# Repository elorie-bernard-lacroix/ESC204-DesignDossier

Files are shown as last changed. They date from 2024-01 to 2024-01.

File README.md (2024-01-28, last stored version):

# ESC204-DesignDossier
A collection of documents, which provide evidence for our design process, design outcomes, and collaboration process for the ESC204 Prototyping Skills Assignment.

Contents and Important Files:
-> 1 - Framing and Initial Ideas
    -> Material here is about the protective case. Iterative design for code/circuitry was started without initial framing
-> 2 - Code and Circuitry
    -> Includes final code (code_final.py) and circuitry (circuit_diagram_final.png)
    -> Code/breadboard layout iterations
    -> Calculations and design decisions described in resistor_calculations.rtf and update_log.rtf
-> 3 - CAD+CAM, MyFab Submission
    -> 
-> 4 - Testing
    -> 
-> 5 - Final Product
    ->

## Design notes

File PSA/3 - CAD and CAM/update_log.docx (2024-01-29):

Update Log – CAD + CAM

Jan 20, 2024

- Started measurements of the board based on Jessica’s design and added it to my pre-existing document from a studio (where we measured the dimensions of the breadboard)
- Found some potential boxes and chose the one outlined in the file “boxes.py_reference”. This box was chosen because of its simplicity and compactness (contributing the usability performance objective). I also specifically chose laser cutting because it had a good chance of being faster and for the aesthetic.
- Looked through the boxes.py export, imported it into Fusion360 (psa-parts) and added the holes corresponding with the lights, the button, and the micro-USB. For this part, simplicity was prioritized, to make sure the result once it was printed was predictable and adjustable (easy to modify) if needed.
- The parts were extruded and uploaded to a second Fusion file (the psa-assembly). I started to assemble them.

Jan 21, 2024

- I finished assembling the parts and realized I could add in an extra component to secure the bread board easily into place. I added holes in the inner sides that fit perfectly with the breadboard attachments and added and inner side in the back of the box for the attachments on that side (the attachment holes only corresponded to the attachments that stook out of the breadboard – so 2 out of 4 sides which is enough to hold it in place, combined with snugness of fit everywhere else).
- This was updated in the Fusion assembly file
- I added the button as well, along with some circular caps that we could try out once it was laser cut.
- I sent the file back to Jessica so she could check over the measurements.
- I exported and imported into AutoCAD, used the MyFab template and made sure everything was up to MyFab expectations (in the correct layer, etc).
- I submitted to MyFab (order: Las7310)

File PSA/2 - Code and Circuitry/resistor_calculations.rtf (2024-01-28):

⁃ current-limiting resistance formula: (actual voltage - forward voltage)/current
⁃ from Pico spec sheet: max current, actual voltage
⁃ from LED spec sheets: min current, forward voltage

RED LED (spec sheet https://cdn-shop.adafruit.com/datasheets/WP7113SRD-D.pdf)
⁃ target luminous intensity relative to 20mA: 0.2
⁃ max current: 14mA
⁃ fwd voltage: 1.82V
⁃ actual voltage: 2.62V
⁃ current-limiting resistance: (2.62-1.82 V)/0.014 A = 57 ohms
⁃ min current: 3mA
⁃ fwd voltage: 1.75V
⁃ actual voltage: 3.1V
⁃ current-limiting resistance: (3.1-1.75 V)/0.003 A = 450 ohms
⁃ valid resistor range: 57-450 ohms
⁃ resistor chosen: 220 ohms

GREEN LED (spec sheet https://www.kingbrightusa.com/images/catalog/SPEC/WP7113SGD.pdf)
⁃ target luminous intensity relative to 20mA: 0.2
⁃ max current: 14mA
⁃ fwd voltage: 2.2V
⁃ actual voltage: 2.62V
⁃ current-limiting resistance: (2.62-2.2)/0.014 = 30 ohms
⁃ min current: 4mA
⁃ fwd voltage: 2V
⁃ actual voltage: 3.1V
⁃ current-limiting resistance: (3.1-2)/0.004 = 275 ohms
⁃ valid resistor range: 30-275 ohms
⁃ resistor chosen: 220 ohms

BLUE LED (spec sheet https://www.kingbrightusa.com/images/catalog/SPEC/WP7113LVBC-D.pdf)
⁃ target luminous intensity relative to 2mA: 0.5
⁃ max current: 14 mA
⁃ fwd voltage: 3.2V
⁃ actual voltage: 2.62V
⁃ current-limiting resistance: (2.62-3.2)/0.014 = -41.4 ohms (ie. resistor not needed)
⁃ min current: 1 mA
⁃ fwd voltage: 2.5V
⁃ actual voltage: 3.25V
⁃ current-limiting resistance: (3.2-2.5)/0.001 = 750 ohms
⁃ valid resistor range: 0-750 ohms
⁃ resistor chosen: 330 ohms (since blue LED is very bright even at low relative intensity)

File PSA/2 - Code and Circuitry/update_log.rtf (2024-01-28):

Jan 19, 2024
- resistance calculations done, followed Lab 1 procedure

Jan 20, 2024
- trying some possible circuit layouts on the breadboard.
- the blue and red LEDs turn on/off at the same time — try pairing them on the breadboard?
- wrote code to achieve the required 3-state toggle system. very straightforward. used a “pressed” variable to ensure that states change only when button is initially pressed (and not when button is held down, released, etc.). linked blue and red LEDs to the same GPIO pin.
- putting the blue and red LEDs in series together with a 220 ohm resistor didn’t work (the blue LED lit up, but not the red). this could be because the resistance used was too high to reach the minimum current requirement for red (~3mA). since 220 ohms is the lowest resistance provided, it’ll be better to put all 3 LEDs separate with their own resistor.
- rewrote code using 3 GPIO pins for LEDs, to reflect the new circuit layout. circuit is working!
- sent pics of circuit layout to Elorie so that she can start the CAD.

Jan 24, 2024
- in myfab. replaced jumper wires with actual wires. had to be careful with wire length so that they lay flat on the breadboard.
- used black wires for ground, red for everything else
- moved button closer to Pico to match up with button presser positioning on lasercut box.
- circuit done!

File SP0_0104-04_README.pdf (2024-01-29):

# ESC204-DesignDossier

A collection of documents, which provide evidence for our design process, design outcomes, and collaboration process for the ESC204 Prototyping Skills Assignment.

Contents and Important Files:
-> 1 - Framing and Initial Ideas
-> Material here is about the protective case. Iterative design for code/circuitry was started without initial framing
-> 2 - Code and Circuitry
-> Includes final code (code_final.py) and circuitry (circuit_diagram_final.png)
-> Code/breadboard layout iterations
-> Calculations and design decisions described in resistor_calculations.rtf and update_log.rtf -> 3 - CAD and CAM
-> Includes the use of the resource, boxes.py (boxes.py_reference.pdf)
-> Includes CAD model of structural elements (psa-parts.stp), their assembly (psa-assembly.stp) and screenshot of the assembly (screenshot_psa-assembly_CAD_model.png)
-> Includes as-built CAM model (MyMaker_LasercutPlywood3mm_Autocad_mm.dwg) and screenshot (screenshot_CAM_model.png)
-> Design decisions described (update_log.docx)
-> Screenshot of confirmation email from MyFab for the Laser cutting order (MyFab confirmation_email.png)
-> 4 - Systems Integration and Testing
-> videos of testing functionality (pressing the button for the lights, assembly and disassembly, rattling, plugging and unplugging micro-USB)
-> videos of testing edge cases (pressing button and holding it, pressing the button very fast) -> Update log to show the process of assembling, modifying, and testing (update_log.docx) -> 5 - Final Product
-> Top, side, and front view of the final product
-> Orthographic picture of the final product, open with visible circuit

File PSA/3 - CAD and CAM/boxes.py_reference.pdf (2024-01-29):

The chosen design from boxes.py was the cardbox with the following measurements

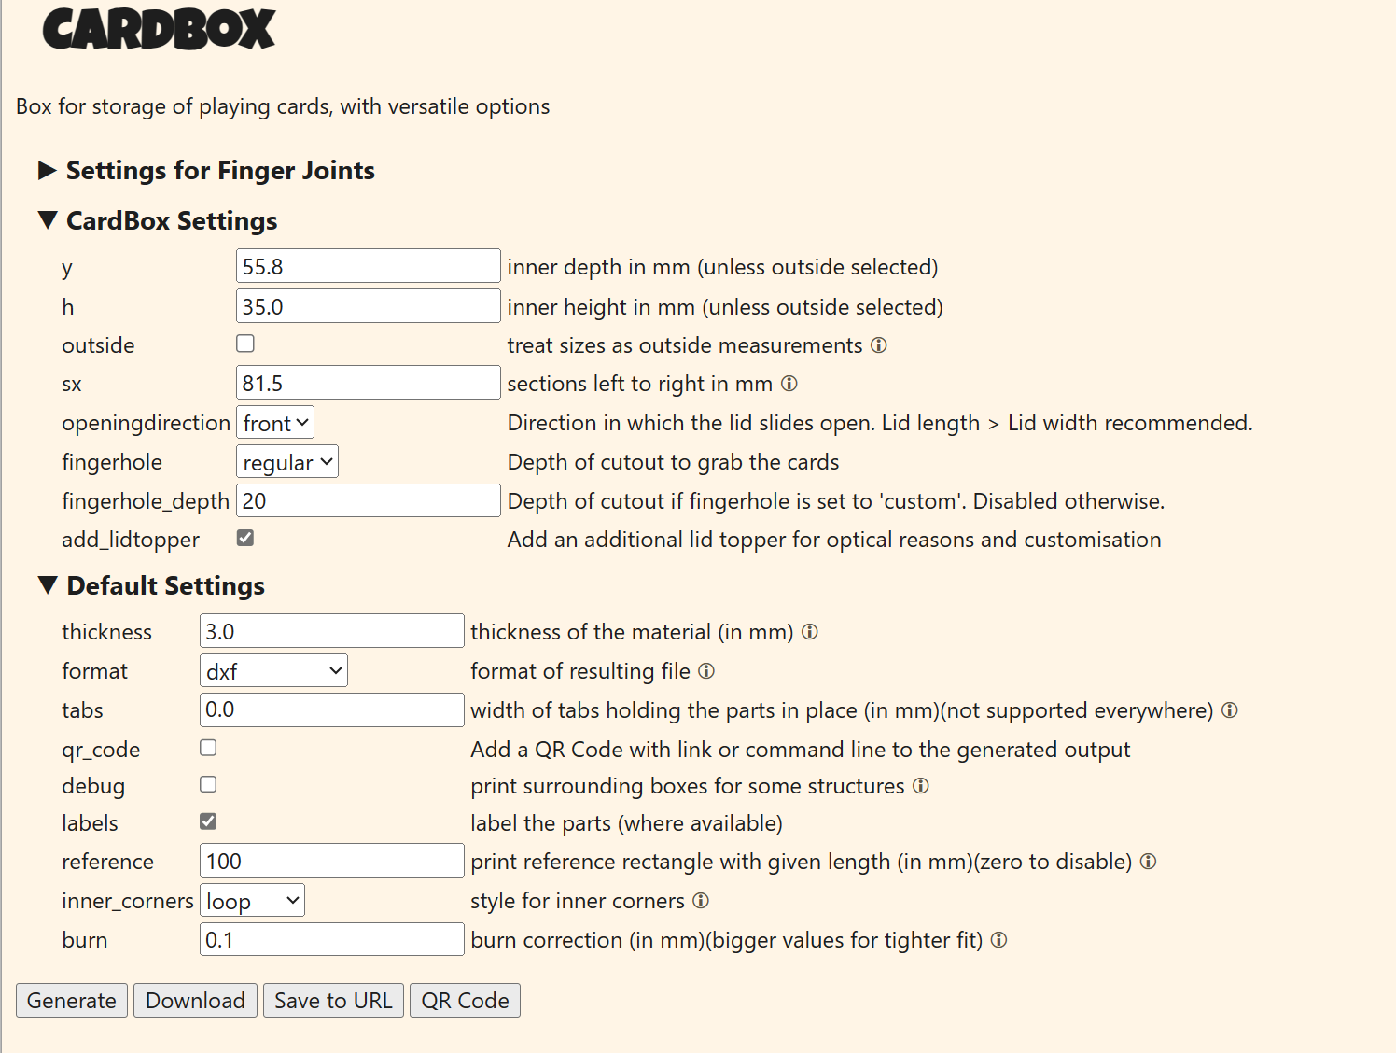
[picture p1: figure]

Design imported into CAD, before adaptations

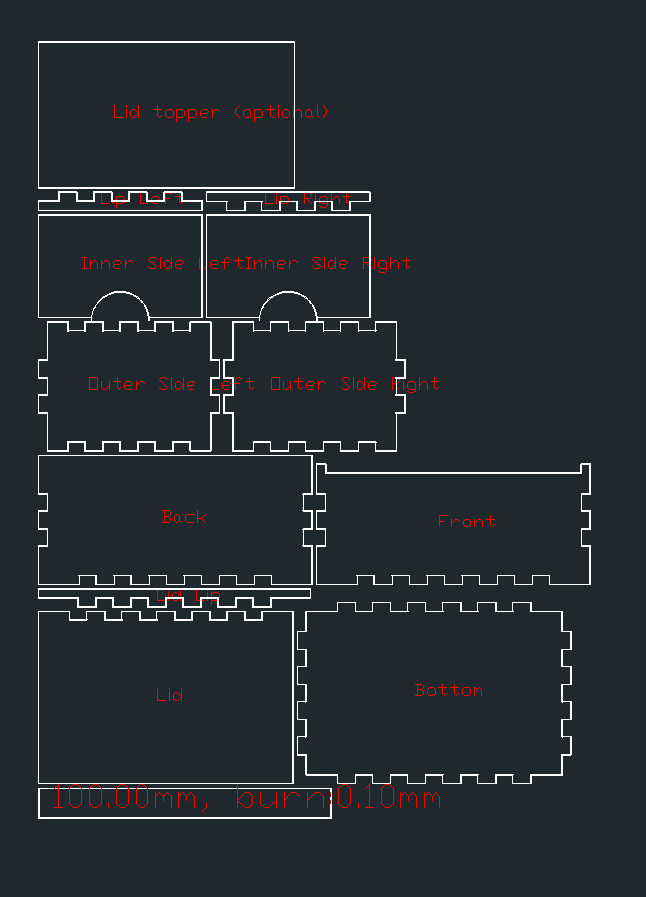
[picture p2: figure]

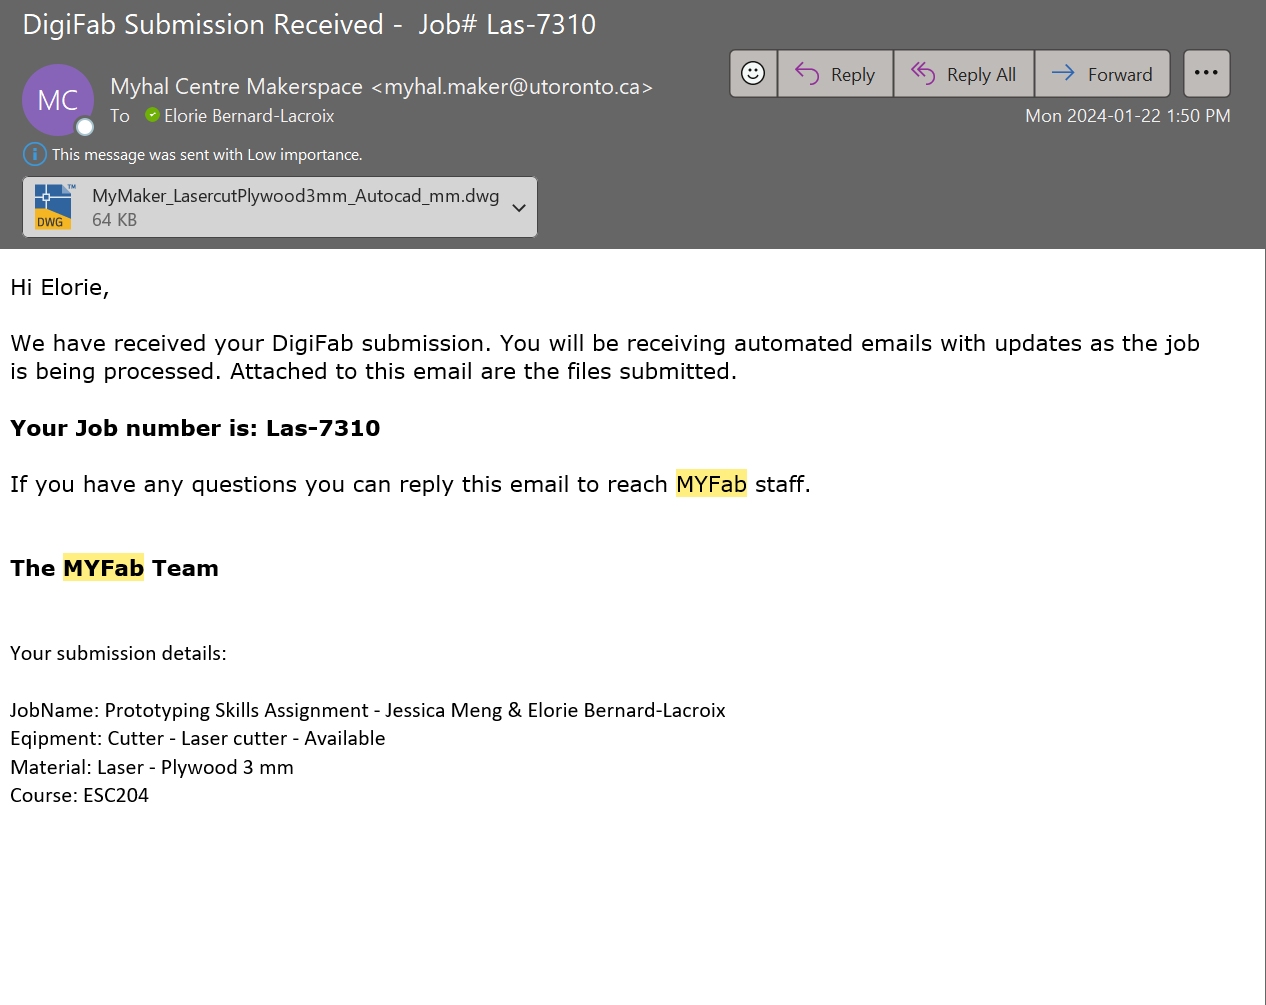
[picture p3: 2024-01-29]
PSA/3 - CAD and CAM/MyFab_confirmation_email.png

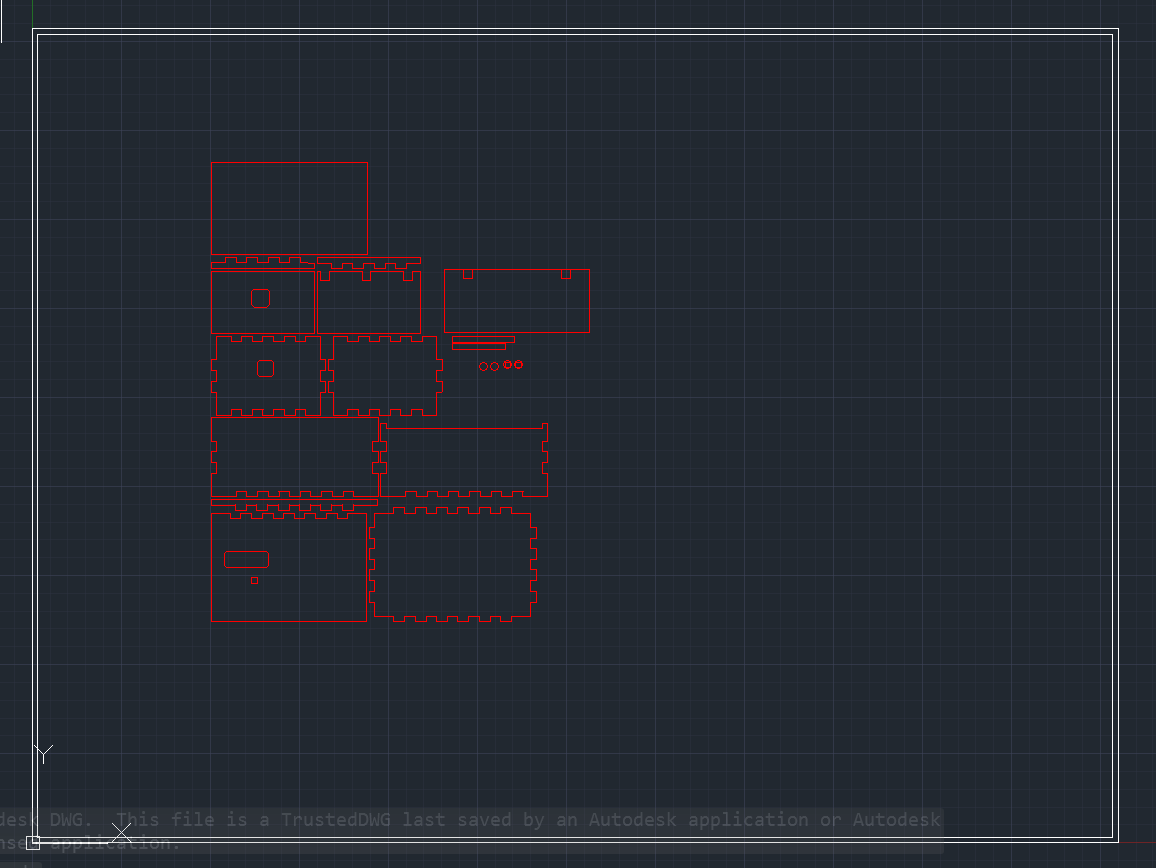
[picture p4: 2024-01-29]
PSA/3 - CAD and CAM/screenshot_CAM_model.png

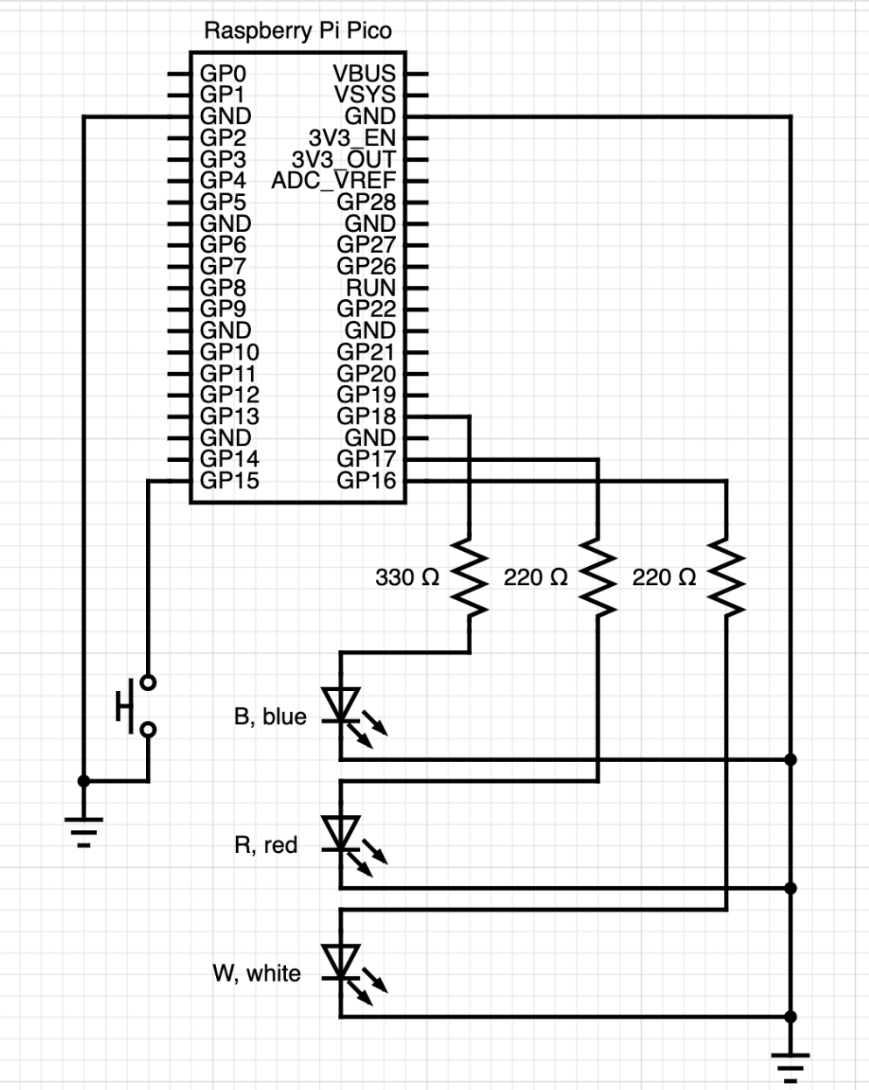
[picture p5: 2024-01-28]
PSA/2 - Code and Circuitry/circuit_diagram_final.png

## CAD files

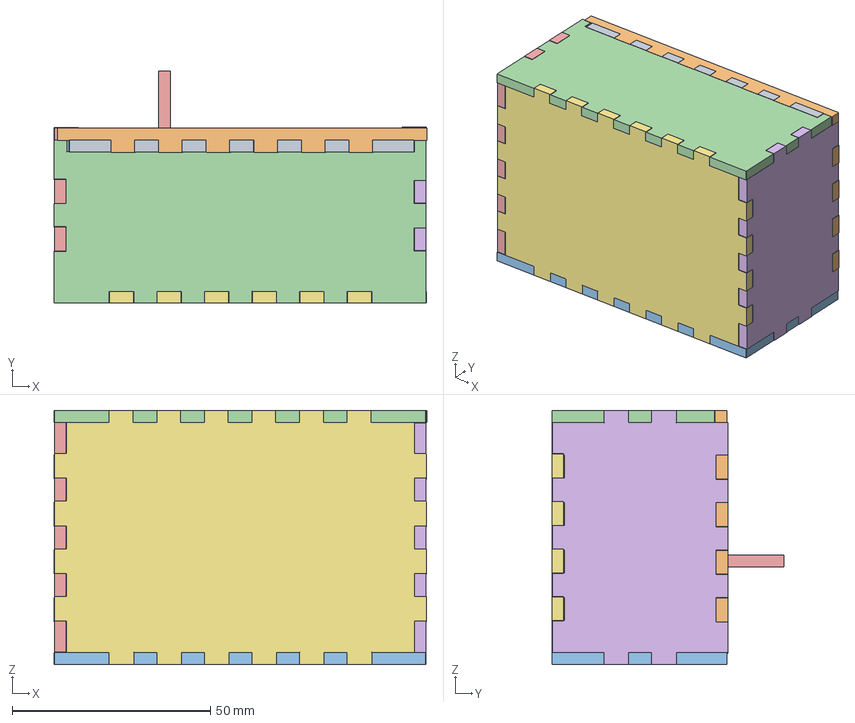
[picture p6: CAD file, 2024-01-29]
PSA/3 - CAD and CAM/psa-assembly (v3).stp
94.0 x 58.6 x 64.1 mm

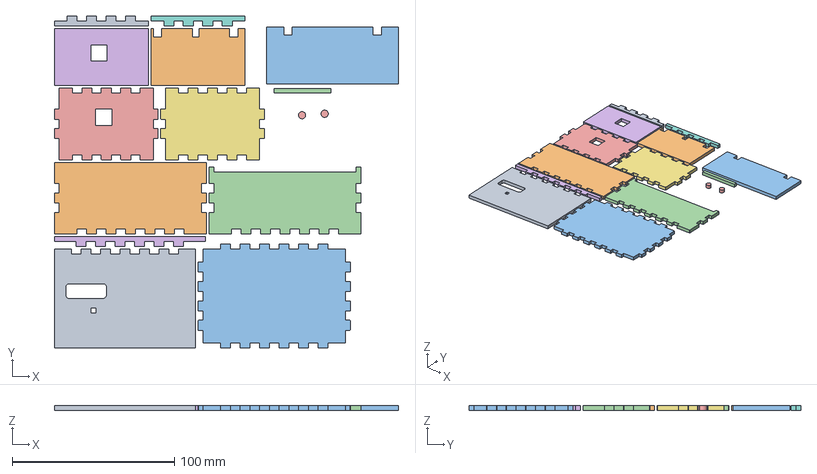
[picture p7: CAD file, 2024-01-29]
PSA/3 - CAD and CAM/psa-parts (final).stp
212.1 x 204.5 x 3.00 mm

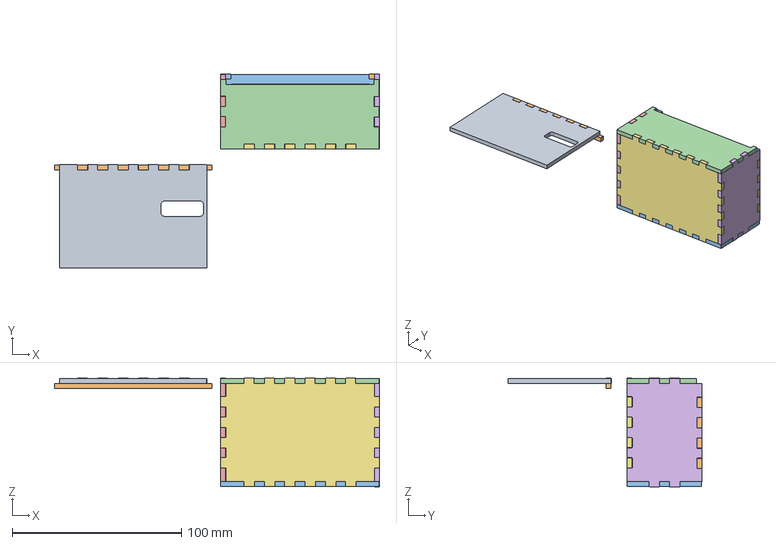
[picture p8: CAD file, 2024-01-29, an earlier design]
PSA/3 - CAD and CAM/psa-assembly (v1).stp
191.9 x 114.6 x 64.1 mm

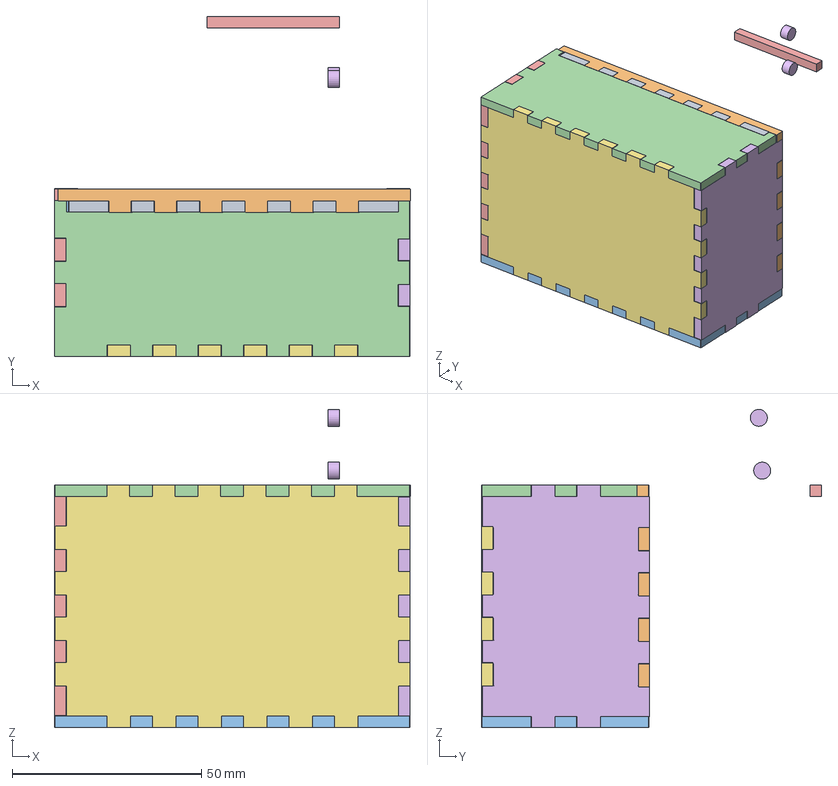
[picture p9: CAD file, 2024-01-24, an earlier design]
PSA/3 - CAD and CAM/psa-assembly (v2).stp
94.0 x 89.7 x 84.0 mm

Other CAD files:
PSA/3 - CAD and CAM/psa-assembly (final).stp
PSA/3 - CAD and CAM/psa-parts (v5).stp
PSA/3 - CAD and CAM/MyMaker_LasercutPlywood3mm_Autocad_mm.dwg
PSA/3 - CAD and CAM/psa-parts (v2).stp
PSA/3 - CAD and CAM/psa-parts (v1).stp
PSA/3 - CAD and CAM/psa-parts (v4).stp
PSA/3 - CAD and CAM/psa-parts (v3).stp

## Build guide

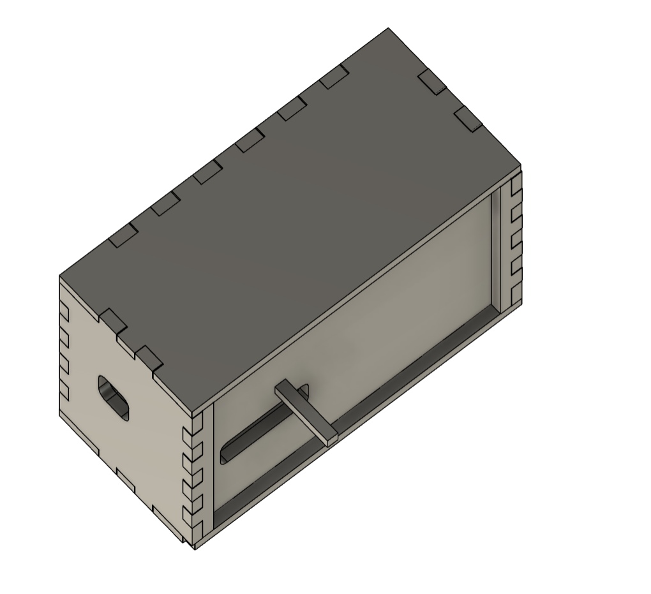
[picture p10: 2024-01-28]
PSA/3 - CAD and CAM/screenshot_psa-assembly_CAD_model.png

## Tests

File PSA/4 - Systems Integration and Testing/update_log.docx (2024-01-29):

Update Log – System integration and testing

Jan 23, 2024

- Picked up order and started assembling with Jessica

Jan 24, 2024

- Sanded some pieces with Jessica because they were slightly thicker than expected.
- Tested ease of assembly and disassembly, as well as lights and USB
- Tested the button functionality.

Jan 25, 2024

- Glued the parts that could be glued together to add more stability and ease of assembly and disassembly for user.
- Took videos of the prototype passing all of our tests

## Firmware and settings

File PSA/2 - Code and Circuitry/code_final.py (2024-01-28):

'''
ESC204 2024S PSA
Task: 3-state toggle w/ button
'''

# Import libraries needed for blinking the LED
import board
import digitalio

# Configure the GPIO pin connected to the LED as a digital output
R = digitalio.DigitalInOut(board.GP17)
R.direction = digitalio.Direction.OUTPUT

G = digitalio.DigitalInOut(board.GP16)
G.direction = digitalio.Direction.OUTPUT

B = digitalio.DigitalInOut(board.GP18)
B.direction = digitalio.Direction.OUTPUT

# Configure the GPIO pin connected to the button as a digital input
button = digitalio.DigitalInOut(board.GP15)
button.direction = digitalio.Direction.INPUT
button.pull = digitalio.Pull.UP # Set internal pull-up resistor

# button.value = False when pressed
# led turns on when led.value = True
pressed = False
state = 1 # 1 is off, 2 is R and B on, 3 is all lights on
        
# Loop so the code runs continuously
while True:
    if (pressed == False and button.value == False): # if button is initially pressed
        pressed = True
        if (state == 3):
            state = 1
            print(state)
        else:
            state += 1
            print(state)
    elif (button.value): # if button is released
        pressed = False
    if (state == 1):
        R.value = False
        G.value = False
        B.value = False
    elif (state == 2):
        R.value = True
        G.value = False
        B.value = True
    else:
        R.value = True
        G.value = True
        B.value = True

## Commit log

2024-01-24 the CAD
    [PSA-0111-05_lasercut_final.dwg, psa-final-assembly.stp]
2024-01-28 Rename PSA/2 - Digital Prototyping, MyFab Submission/psa-final-assembly.stp to PSA/3 - CAD+CAM, MyFab Submissionpsa-final-assembly.stp
    [3 - CAD+CAM, MyFab Submissionpsa-final-assembly.stp, psa-final-assembly.stp]
2024-01-28 Update and rename PSA/3 - CAD+CAM, MyFab Submissionpsa-final-assembly.stp to PSA/3 - CAD+CAM, MyFab Submission/psa-final-assembly.stp
    [psa-final-assembly.stp]
2024-01-28 Rename Video of edge case - pressing and holding the button.MOV to Video of edge case - pressing and holding the button.MOV
2024-01-28 Rename Video of functionality - assembly.MOV to Video of functionality - assembly.MOV
